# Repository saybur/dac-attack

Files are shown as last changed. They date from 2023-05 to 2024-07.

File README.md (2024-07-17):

DAC Attack!
===========

A small [S/PDIF](https://en.wikipedia.org/wiki/S/PDIF) to
[line-level](https://en.wikipedia.org/wiki/Line_level) audio adapter design.
The intended use case is with some versions of
[ZuluSCSI](https://zuluscsi.com/), though the design should work with any
S/PDIF compatible output source generating a TTL-compatible signal.

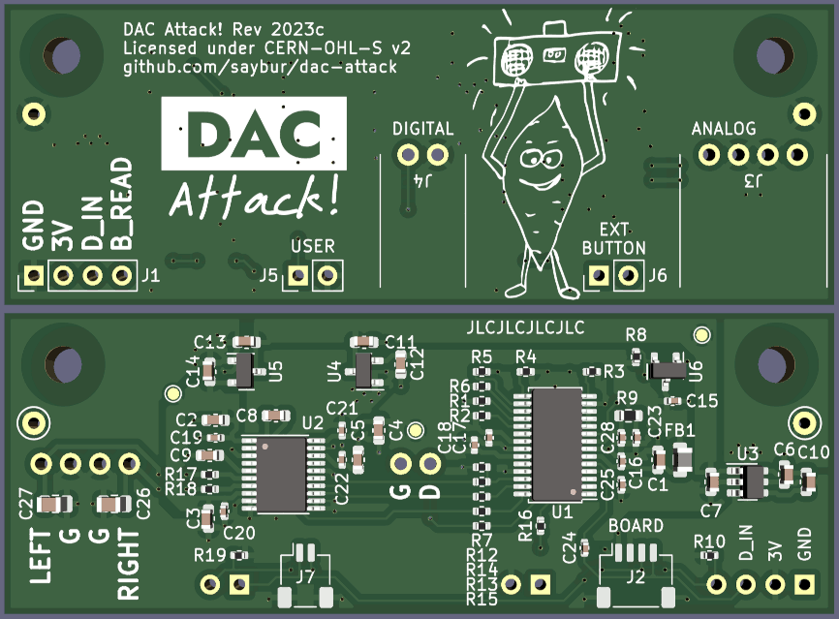
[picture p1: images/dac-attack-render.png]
Rendering of the front and back of a DAC Attack 2022c board


Used with a compatible board, and the appropriate firmware, this allows sending
audio to a retro computer. See later sections for usage information.

As of this writing, only some ZuluSCSI variants offer audio output. This list
may change in the future. Refer to the ZuluSCSI project page for details about
audio output support.

License and Disclaimer
----------------------

This project is made available under the CERN Open Hardware Licence
strongly-reciprocal variant version 2, available at [LICENSE](LICENSE).

This source is distributed WITHOUT ANY EXPRESS OR IMPLIED WARRANTY, INCLUDING
OF MERCHANTABILITY, SATISFACTORY QUALITY AND FITNESS FOR A PARTICULAR PURPOSE.
Please see the CERN-OHL-S v2 for applicable conditions.

ZuluSCSI&trade; is a registered trademark of Rabbit Hole Computing&trade;, used
with permission.

Assembly
--------

The author has had JLCPCB assemble these boards as prototypes. The files
`dac-attack-bom.csv` and `dac-attack-top-pos.csv` files were used successfully,
though caution should still be excercised: other open-source hardware projects
have reported some inconsistency in individual orders using files like these.

Adding through-hole components to assembled boards is relatively
straightforward. The choice of what connectors to solder is up to the user:

- 'analog' provides standard line-level output for sending to a sound card.
- 'digital' provides TTL-level S/PDIF from the CS8416 chip, which should
  _theoretically_ be suitable for sending to a sound card with a digital-in
  connector, ~~those this use case is NOT TESTED~~ florian3 on Vogons reports
  this is working fine, thanks for testing!
- 'ext button' provides a place to attach a button for the **B_READ** line.
- 'user' is connected to the U pin of the CS8416. This feature is not tested
  and this pad can be left vacant.
- The four pads for **G**, **3V**, **D_IN**, and **B_READ** are available if
  you do not want to use the modular connector. See the later section for
  hookup information.

Part numbers for through-hole parts are in [bom-full.csv](bom-full.csv).

Installation
------------

The screw holes on the board are spaced to match a 2.5" hard drive, which is
the same pattern on most ZuluSCSI boards. Use standoffs to prevent shorting
connections. An example mount is shown below. The full BOM has some options,
which you can probably also find at your local hardware store or a convenient
online retailer.

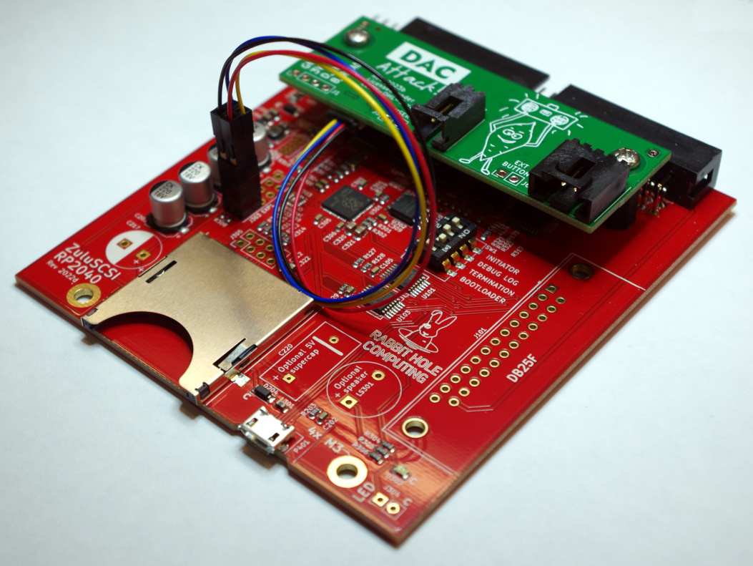
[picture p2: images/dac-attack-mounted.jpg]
An example of a DAC Attack mounted to a 2022d ZuluSCSI


Most parent boards use either a 0.1" holes _or_ a matching 4-pin modular
connector. Instructions vary between these two board types.

__Important note:__ DAC Attack uses a 4-pin connector that matches common
hobbyist I2C formats; however, the board is __not compatible__ with I2C.

### 0.1 Connectors

**Carefully** solder a socket on the parent board. Most will need either a 2x2
or 1x4 connector for this. Example parts to order are in the BOM. You only need
to solder to points labeled **GND**, **3V0**, **SCL**, and **SDA** on the
bottom of the board. Again, use great care during this process to avoid
damaging anything.

Once soldered, connect a suitable cable from the socket to the DAC's modular
connector. Potential options are listed in the BOM. If the DAC's modular
connector is not populated, or you would prefer not to use it, the separate
labeled points on the DAC may be used instead.

If using the modular cable pin breakout version, colors should correspond as
follows:

- Black: GND
- Red: VCC (3V)
- Blue: B_READ ('SDA' label)
- Yellow: D_IN ('SCL' label)

### Modular Connector

If your parent board is equipped with a 1x4 modular connector, you're all set:
just connect the board to the DAC.

If the parent board does not have a modular connector, the most straightforward
option is to add the modular connector, likely part _BM04B-SRSS-TB(LF)(SN)_.

Cabling
-------

Once you have installed the board and applied correct firmware (if needed), all
that remains is connecting the 'analog' port to a suitable target. Most period-
correct sound cards will use either a 3-pin or 4-pin cable for connecting a CD
drive. This pinout is also compatible with the one used on retro Mac computers.

It is recommended to test your configuration to determine if stereo audio is
being handled appropriately. If it is not, rotate the cable in the socket.

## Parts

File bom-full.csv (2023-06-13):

refs | desc | jlcpcb | jlctype | jlcpcb_fp | digikey | notes
C1-7 | 10uF | C96446 | basic | 603 |  | X5R, only option in basic
C8-14 | 2.2uF | C23630 | basic | 603 |  | X5R, C50254 for X7R but in 1206
C15-22 | 100nF | C1525 | basic | 402 |  | ok
C23-25 | 22nF | C1532 | basic | 402 |  | ok
C26-27 | 2.2nF | C28260 | basic | 805 |  | C0G, but note size
C28 | 1nF | C161523 | extended | 402 |  | Needs to be C0G. See C1523 for X7R
FB1 | GZ2012D601TF Ferrite | C1017 | basic | 805
J1 | 1x4 2.54mm Pins | n/a |  |  | 2057-PH1-04-UA-ND
J2 | 4 pin JST SH Socket | C160404 | extended | - | 455-1804-1-ND
J3 | Analog Audio | n/a |  |  | WM4902-ND
J4 | Digital Audio | n/a |  |  | WM4900-ND
J5-6 | 1x2 2.54mm Pins | n/a |  |  | 2057-PH1-02-UA-ND
J7 | 2 pin JST SH Socket | C160402 | extended | DNP | 455-1802-1-ND
R1-8 | 47Kohm 0402 | C25792 | basic | 402
R9 | 3Kohm 0603 | C4211 | basic | 603 |  | 0402 not available in basic
R10 | 10Kohm 0402 | C25744 | basic | 402
R12-16 | 22ohm 0402 | C25092 | basic | 402
R17-19 | 470ohm 0402 | C25117 | basic | 402
U1 | CS8416-CZZR | C11163 | extended | TSSOP-28
U2 | PCM5101APWR | C2667024 | extended | TSSOP-20
U3 | SD6210A | C250809 | extended | SOT-23-6
U4-5 | XC6206P332MR | C5446 | basic | SOT-23-3L
U6 | MAX809TEUR+T | C16711 | extended | SOT-23 |  | most SOT-23-3 ‘809T' options OK
optional components
- | 2x2 2.54mm Socket |  |  |  | S7105-ND
- | 1x4 2.54mm Socket |  |  |  | S7038-ND
- | Modular Cable |  |  |  | 1528-4210-ND
- | Modular Cable w/ Pins |  |  |  | 1568-1709-ND
- | Hex Standoffs (10mm) |  |  |  | 36-24337-ND | See 1528-2339-ND for more options.
- | Hex Standoffs (15mm) |  |  |  | 36-24339-ND | Needed on Compact and Homebrew

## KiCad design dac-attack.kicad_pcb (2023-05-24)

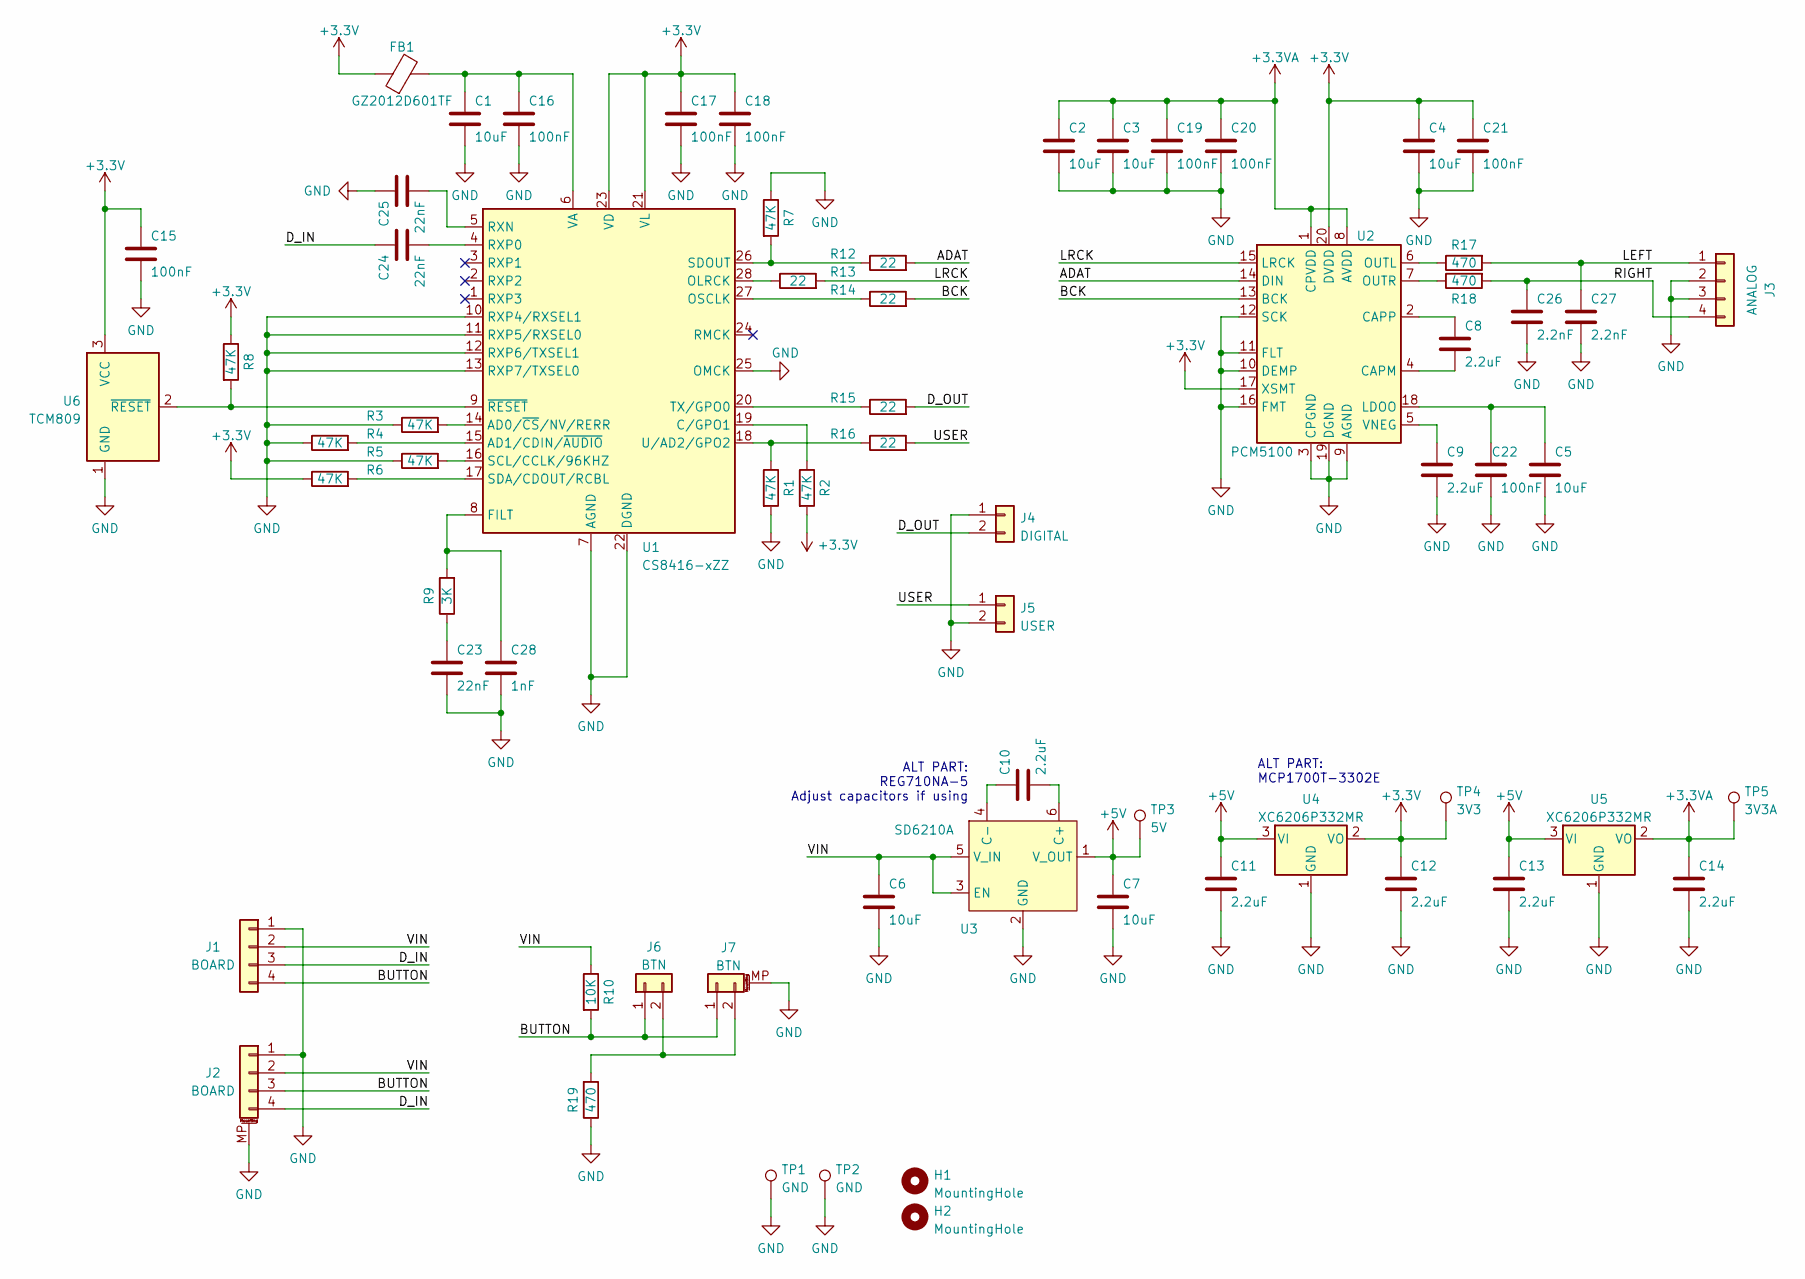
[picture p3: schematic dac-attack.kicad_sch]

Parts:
C1, C2, C3, C4, C5, C6, C7: 10uF; C_0603_1608Metric
C8, C9, C10, C11, C12, C13, C14: 2.2uF; C_0603_1608Metric
C15, C16, C17, C18, C19, C20, C21, C22: 100nF; C_0402_1005Metric
C23, C24, C25: 22nF; C_0402_1005Metric
C26, C27: 2.2nF; C_0805_2012Metric
C28: 1nF; C_0402_1005Metric
FB1: GZ2012D601TF; L_0805_2012Metric
H1, H2: MountingHole; MountingHole_3.2mm_M3
J1: BOARD; PinHeader_1x04_P2.54mm_Vertical
J2: BOARD; JST_SH_SM04B-SRSS-TB_1x04-1MP_P1.00mm_Horizontal
J3: ANALOG; 0705530003
J4: DIGITAL; 0705530001
J5: USER; PinHeader_1x02_P2.54mm_Vertical
J6: BTN; PinHeader_1x02_P2.54mm_Vertical
J7: BTN; JST_SH_SM02B-SRSS-TB_1x02-1MP_P1.00mm_Horizontal
R1, R2, R3, R4, R5, R6, R7, R8: 47K; R_0402_1005Metric
R9: 3K; R_0603_1608Metric
R10: 10K; R_0402_1005Metric
R12, R13, R14, R15, R16: 22; R_0402_1005Metric
R17, R18, R19: 470; R_0402_1005Metric
TP1, TP2: GND; TestPoint_Keystone_5000-5004_Miniature
TP3: 5V; TestPoint_Pad_D1.0mm
TP4: 3V3; TestPoint_Pad_D1.0mm
TP5: 3V3A; TestPoint_Pad_D1.0mm
U1: CS8416-xZZ; TSSOP-28_4.4x9.7mm_P0.65mm
U2: PCM5100; TSSOP-20_4.4x6.5mm_P0.65mm
U3: SD6210A; SOT-23-6
U4, U5: XC6206P332MR; SOT-23
U6: TCM809; SOT-23

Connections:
+3.3VA: C2.1, C3.1, C14.1, C19.1, C20.1, TP5.1, U2.1 (CPVDD), U2.8 (AVDD), U5.2 (VO)
+3V3: C4.1, C12.1, C15.1, C17.1, C18.1, C21.1, FB1.1, R2.2, R6.1, R8.1, TP4.1, U1.21 (VL), U1.23 (VD), U2.17 (XSMT), U2.20 (DVDD), U4.2 (VO), U6.3 (VCC)
+5V: C7.1, C11.1, C13.1, TP3.1, U3.1 (V_OUT), U4.3 (VI), U5.3 (VI)
/ADAT: R12.2, U2.14 (DIN)
/BCK: R14.2, U2.13 (BCK)
/BUTTON: J1.4, J2.3, J6.1, J7.1, R10.2
/D_IN: C24.1, J1.3, J2.4
/D_OUT: J4.2, R15.2
/LEFT: C27.1, J3.1, R17.2
/LRCK: R13.2, U2.15 (LRCK)
/RIGHT: C26.1, J3.4, R18.2
/USER: J5.1, R16.2
/VIN: C6.1, J1.2, J2.2, R10.1, U3.3 (EN), U3.5 (V_IN)
GND: C1.2, C2.2, C3.2, C4.2, C5.2, C6.2, C7.2, C9.2, C11.2, C12.2, C13.2, C14.2, C15.2, C16.2, C17.2, C18.2, C19.2, C20.2, C21.2, C22.2, C23.2, C25.1, C26.2, C27.2, C28.2, J1.1, J2.1, J2.MP (MountPin), J3.2, J3.3, J4.1, J5.2, J7.MP (MountPin), R1.2, R3.1, R4.1, R5.1, R7.1, R19.1, TP1.1, TP2.1, U1.7 (AGND), U1.10 (RXP4/RXSEL1), U1.11 (RXP5/RXSEL0), U1.12 (RXP6/TXSEL1), U1.13 (RXP7/TXSEL0), U1.22 (DGND), U1.25 (OMCK), U2.3 (CPGND), U2.9 (AGND), U2.10 (DEMP), U2.11 (FLT), U2.12 (SCK), U2.16 (FMT), U2.19 (DGND), U3.2 (GND), U4.1 (GND), U5.1 (GND), U6.1 (GND)
unnamed: C1.1, C16.1, FB1.2, U1.6 (VA)
unnamed: C8.1, U2.2 (CAPP)
unnamed: C8.2, U2.4 (CAPM)
unnamed: C9.1, U2.5 (VNEG)
unnamed: C10.1, U3.4 (C-)
unnamed: C10.2, U3.6 (C+)
unnamed: C5.1, C22.1, U2.18 (LDOO)
unnamed: C23.1, R9.1
unnamed: C24.2, U1.4 (RXP0)
unnamed: C25.2, U1.5 (RXN)
unnamed: C28.1, R9.2, U1.8 (FILT)
unnamed: J6.2, J7.2, R19.2
unnamed: R1.1, R16.1, U1.18 (U/AD2/GPO2)
unnamed: R2.1, U1.19 (C/GPO1)
unnamed: R3.2, U1.14 (AD0/~CS/NV/RERR)
unnamed: R4.2, U1.15 (AD1/CDIN/~AUDIO)
unnamed: R5.2, U1.16 (SCL/CCLK/96KHZ)
unnamed: R6.2, U1.17 (SDA/CDOUT/RCBL)
unnamed: R8.2, U1.9 (~RESET), U6.2 (~RESET)
unnamed: R7.2, R12.1, U1.26 (SDOUT)
unnamed: R13.1, U1.28 (OLRCK)
unnamed: R14.1, U1.27 (OSCLK)
unnamed: R15.1, U1.20 (TX/GPO0)
unnamed: R17.1, U2.6 (OUTL)
unnamed: R18.1, U2.7 (OUTR)

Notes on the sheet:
ALT PART: MCP1700T-3302E
ALT PART: REG710NA-5 Adjust capacitors if using

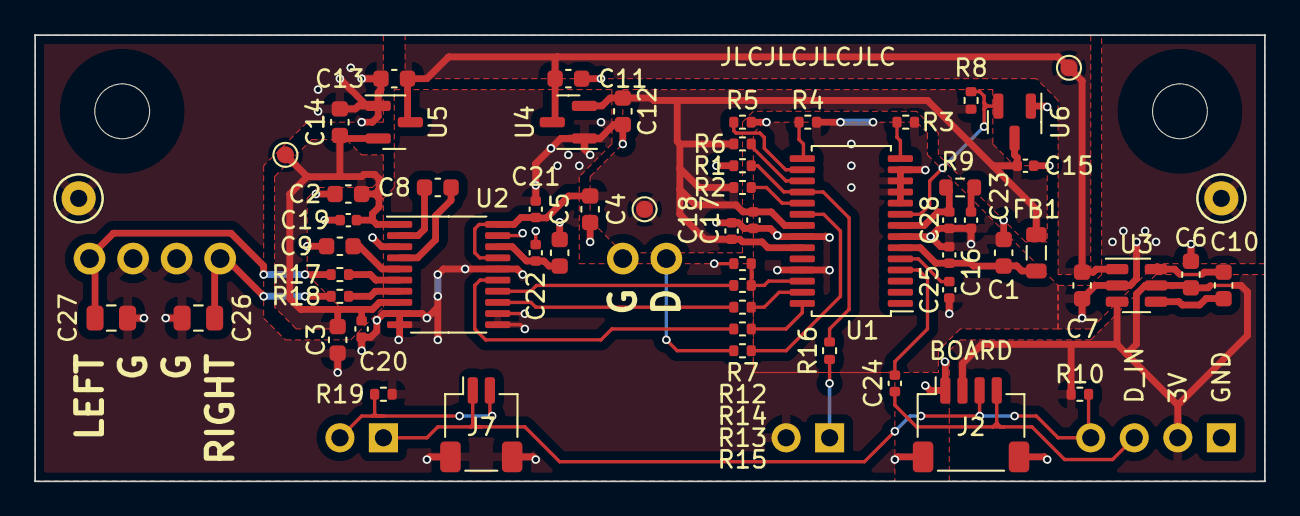
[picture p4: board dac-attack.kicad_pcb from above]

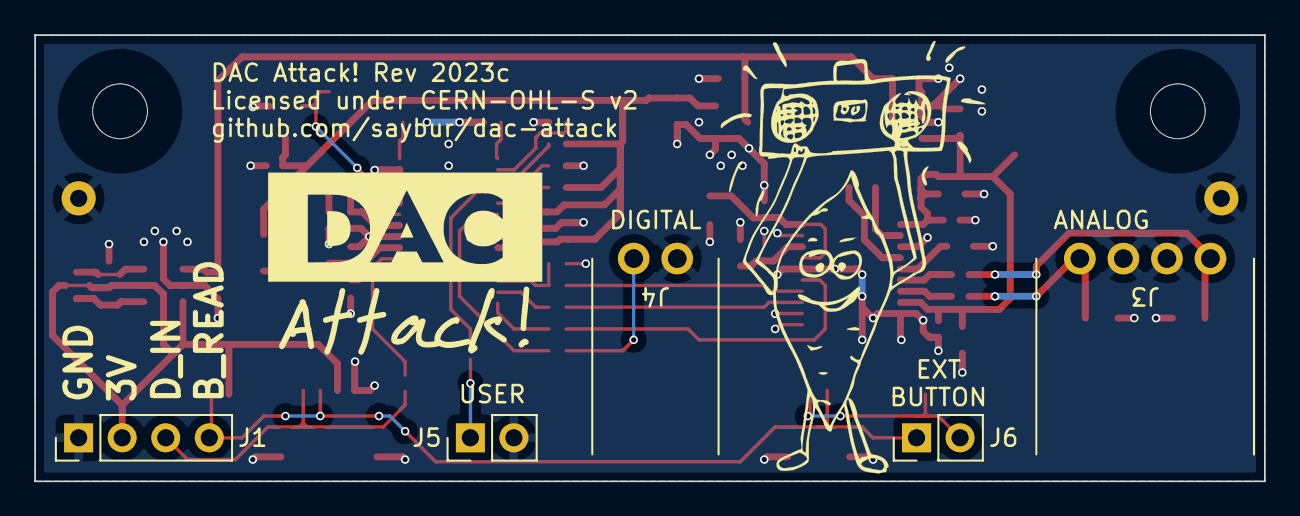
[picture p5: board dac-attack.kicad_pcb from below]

Board: 2 copper layers, 71.8 x 26.0 mm, 67 parts (5 on the bottom side), 39 nets.

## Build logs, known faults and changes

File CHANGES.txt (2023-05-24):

DESIGN CHANGES

Refer to section 3.3.b of the license for information that must be included in
this document.

- 14 May 2023, rev 2023b: first functional design

- 24 May 2023, rev 2023c: minor layout changes:
    - updated silkscreen to include link to repository; labeled modular
      connector.
    - shifted mounting holes to ease installation on compact board variants.

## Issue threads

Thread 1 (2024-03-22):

Support of ZuluSCSI Mini RP2040

leonkiriliuk, 2024-03-22:
Is adding support to the ZuluSCSI Mini RP2040 external ever possible? I see that the SDA and SCL pins are available but I suspect a board revision might be required.

How do external SCSI drives even get their audio back into the computer when playing music CDs? Do they feed the analog audio into the mic in port of sound cards?

Picture of PCB can be seen here: https://store.rabbitholecomputing.com/ZuluSCSI-Mini-RP2040-p/zuluscsi-mini-rp2040-db25.htm

saybur, 2024-03-23:
I did a quick glance at the ZuluSCSI firmware source and I didn't see any GPIO changes that would affect the expansion pins on that model. That said I don't own one of those so I can't test to be 100% sure.

If you want to manually check, you could use a multimeter and verify continuity between the RP2040 GPIO14 (pin 17) to SDA, and GPIO15 (pin 18) to SCL. It might also be worth opening a discussion topic over at the main project or emailing RHC, they are obviously the authority on how their boards are wired and could get you an official answer.

The physical limitations are probably a bigger deal IMHO. This might be a case where hooking up a Toslink module (Everlight PLT237/T10WH) is the way to go rather than fabbing a DAC yourself - you'll probably end up with an external DAC anyway, so might as well keep the custom hardware as simple as possible.

Closed 2024-05-25.

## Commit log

2023-04-27 Initial design.
    [dac-attack-B_Cu.gbl, dac-attack-B_Mask.gbs, dac-attack-B_Paste.gbp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]
2023-05-09 Initial work on revision 2023b.
    [dac-attack-B_Cu.gbl, dac-attack-B_Mask.gbs, dac-attack-B_Paste.gbp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]
2023-05-14 Tweaks to 2023b
    Fixed one net, widened traces, made some minor silkscreen changes.
    [dac-attack-B_Cu.gbl, dac-attack-B_Mask.gbs, dac-attack-B_Paste.gbp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]
2023-05-14 Added missing BOM / positioning files.
    [bom-full.csv, dac-attack-bom.csv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]
2023-05-24 Board revision 2023c.
    No component layout changes, just minor tweaks to mounting holes and silkscreening.
    [dac-attack-B_Cu.gbl, dac-attack-B_Mask.gbs, dac-attack-B_Paste.gbp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]
2023-05-24 Add J2 to manufacturing and list some parts for TH pins.
    [bom-full.csv, dac-attack-bom.csv]
2023-05-24 Added some optional BOM components.
    [bom-full.csv]
2023-06-13 Added note about compatibility with some board revisions.
    [bom-full.csv]

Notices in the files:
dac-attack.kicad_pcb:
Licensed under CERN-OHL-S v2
